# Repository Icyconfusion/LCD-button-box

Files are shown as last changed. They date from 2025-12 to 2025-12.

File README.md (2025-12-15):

# LCD-button-box
A DIY stream deck style button box using a 3.5" LCD, tact switches and an ESP32 Devkit V1.

The button box uses an LCD seated at the bottom of the case. Above that, a PCB is suspended, containing the necessary tact switches. The PCB has square cutout holes to show the LCD image through. To press the buttons, there is a 3d printed stand on each set of 4 switches (one button), holding a clear acrylic square. Through this mechanism, the LCD is visible, and pressing the acylic presses the tact switches, registering a keypress. The bottom right button functions as a change layer button, where pressing that will cycle the button box to a new 'layer', with different icons and key outputs. 

The case is made using two parts, a base and a top. The base has 4 'legs' inside it to hold the lcd. 
 
Above that, there is a perimeter ledge for the PCB to sit on. 

The top attaches to the base using 4xM3 heatset inserts. 



The ESP32 and switches are soldered to the PCB, and headers are soldered in place of the LCD. Jumper wires connect these headers down, underneath the LCD and into the pins on the bottom of the LCD.



The button box connects to devices by bluetooth, but requires a micro usb power source. The button box outputs macros using a combination of CTRL, SHIFT, ALT and F14+ keys to ensure unique macros.

Bill of materials
1x ESP32 Devkit V1

24x Tactile switch 6x6x5mm

1x 3.5" TFT 480x320 LCD screen

1x 40 pin male headers

20x Female - female jumper wires

3d printed parts

Acrylic sheet

PCB

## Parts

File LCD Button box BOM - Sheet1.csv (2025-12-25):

Product name | Quantity | Description | Supplier | Cost (USD) | Link
Tact Switch | 24 | A 6x6x5mm tactile switch. Comes in a pack of 50. | TEMU | 2.13 | https://www.temu.com/au/50pcs-6-6-5mm-tactile--pin-micro-push-button-g-601099520633185.html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
LCD | 1 | 3.5" TFT 480x320 LCD screen - Amazon is the cheapest place for this product - cheaper than TEMU and aliexpress | Amazon AU | 16.86 | https://www.amazon.com.au/3-5inch-480X320-Display-Module-Without/dp/B0DB25WKB3
Header | 1 | 1x40 pin 2.54mm male pin header | Jaycar Electronics | 0.73 | https://www.jaycar.com.au/40-pin-header-terminal-strip/p/HM3212
Acrylic SHeet | 1 | An A5 acrylic sheet to be cut into small squares - Amazon is cheaper than aliexpress and temu for this product | Amazon AU | 8.26 | https://www.amazon.com.au/gp/product/B0FC6TMFG9/ref=ox_sc_act_image_1?smid=A3H79FG5MEROR8&th=1

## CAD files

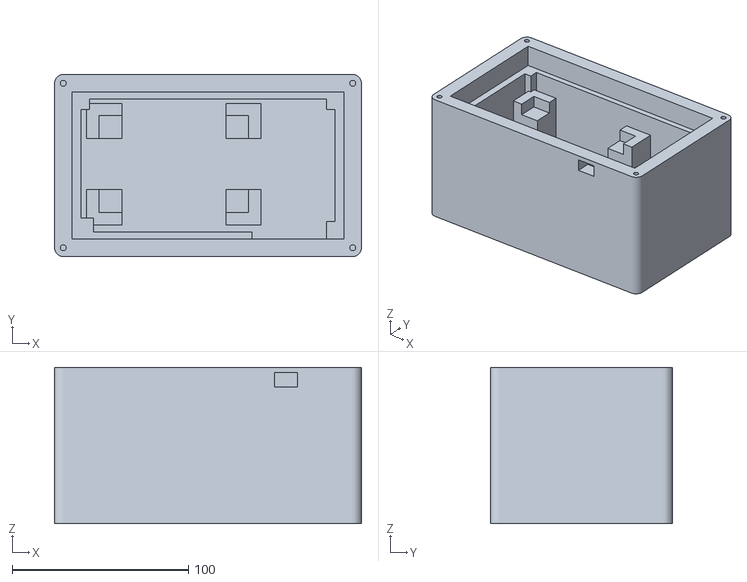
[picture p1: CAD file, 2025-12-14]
CAD/lcd button box case base.stl
174.2 x 103.3 x 88.6

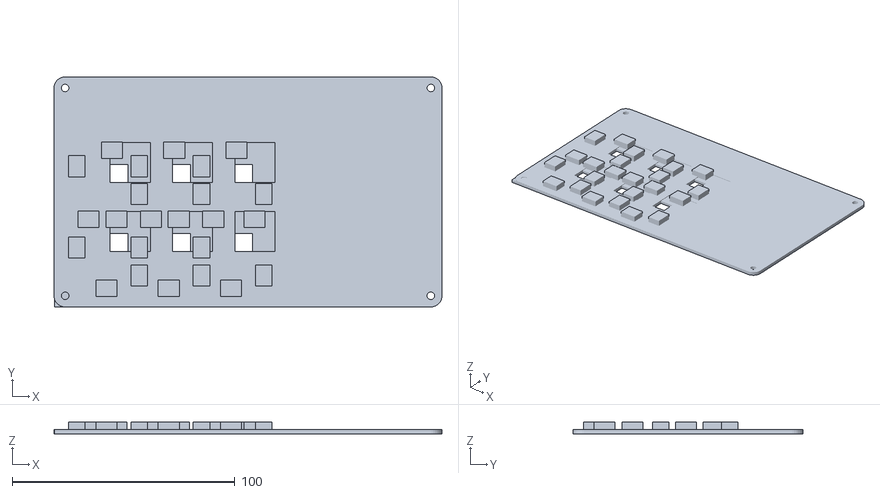
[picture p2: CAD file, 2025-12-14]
CAD/LCD Button box top.stl
174.2 x 103.4 x 5.20

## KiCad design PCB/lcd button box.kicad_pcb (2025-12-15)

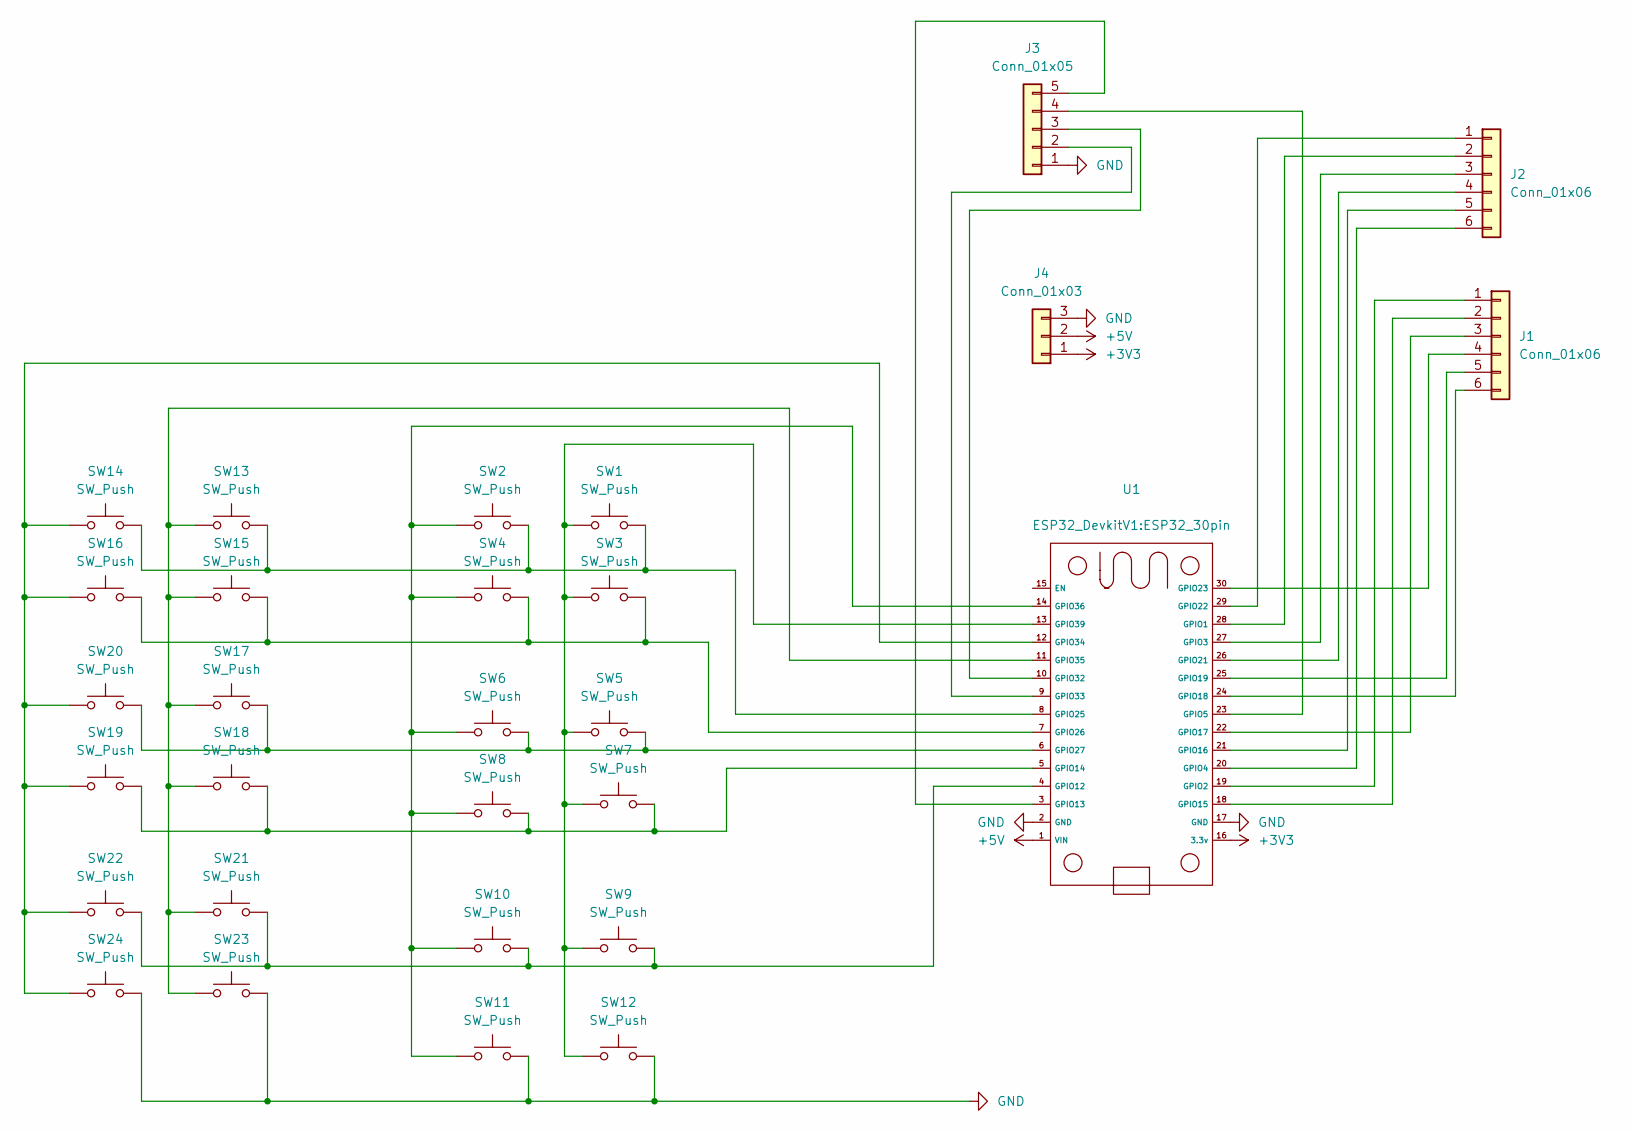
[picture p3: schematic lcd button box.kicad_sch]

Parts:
J1, J2: Conn_01x06; PinHeader_1x06_P2.54mm_Vertical
J3: Conn_01x05; PinHeader_1x05_P2.54mm_Vertical
J4: Conn_01x03; PinHeader_1x03_P2.54mm_Vertical
SW1, SW2, SW3, SW4, SW5, SW6, SW7, SW8, SW9, SW10, SW11, SW12, SW13, SW14, SW15, SW16, SW17, SW18, SW19, SW20, SW21, SW22, SW23, SW24: SW_Push; SW_PUSH_6mm
U1: ESP32_30pin

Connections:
+3V3: J4.1, U1.16 (3.3v)
+5V: J4.2, U1.1 (VIN)
GND: J3.1, J4.3, SW11.2, SW12.2, SW23.2, SW24.2, U1.2 (GND), U1.17 (GND)
unnamed: J1.1, U1.19 (GPIO2)
unnamed: J1.2, U1.18 (GPIO15)
unnamed: J1.3, U1.22 (GPIO17)
unnamed: J1.4, U1.30 (GPIO23)
unnamed: J1.5, U1.25 (GPIO19)
unnamed: J1.6, U1.24 (GPIO18)
unnamed: J2.1, U1.29 (GPIO22)
unnamed: J2.2, U1.28 (GPIO1)
unnamed: J2.3, U1.27 (GPIO3)
unnamed: J2.4, U1.26 (GPIO21)
unnamed: J2.5, U1.21 (GPIO16)
unnamed: J2.6, U1.20 (GPIO4)
unnamed: J3.2, U1.9 (GPIO33)
unnamed: J3.3, U1.10 (GPIO32)
unnamed: J3.4, U1.23 (GPIO5)
unnamed: J3.5, U1.3 (GPIO13)
unnamed: SW9.2, SW10.2, SW21.2, SW22.2, U1.4 (GPIO12)
unnamed: SW7.2, SW8.2, SW18.2, SW19.2, U1.5 (GPIO14)
unnamed: SW1.2, SW2.2, SW13.2, SW14.2, U1.8 (GPIO25)
unnamed: SW3.2, SW4.2, SW15.2, SW16.2, U1.7 (GPIO26)
unnamed: SW5.2, SW6.2, SW17.2, SW20.2, U1.6 (GPIO27)
unnamed: SW14.1, SW16.1, SW19.1, SW20.1, SW22.1, SW24.1, U1.12 (GPIO34)
unnamed: SW13.1, SW15.1, SW17.1, SW18.1, SW21.1, SW23.1, U1.11 (GPIO35)
unnamed: SW2.1, SW4.1, SW6.1, SW8.1, SW10.1, SW11.1, U1.14 (GPIO36)
unnamed: SW1.1, SW3.1, SW5.1, SW7.1, SW9.1, SW12.1, U1.13 (GPIO39)

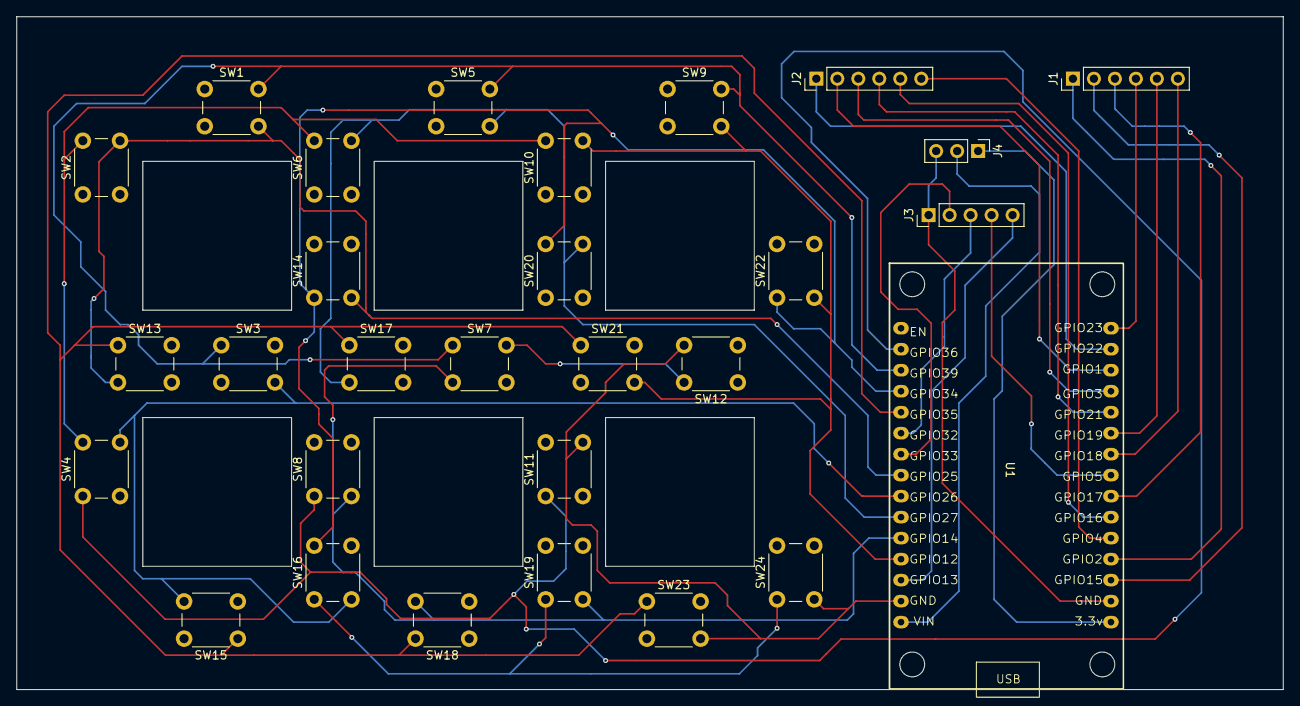
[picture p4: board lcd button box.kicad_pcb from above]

Board: 2 copper layers, 153.2 x 81.4 mm, 29 parts (0 on the bottom side), 28 nets.

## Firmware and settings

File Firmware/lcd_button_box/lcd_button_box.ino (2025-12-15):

// hello world

#include <BleKeyboard.h>
BleKeyboard bleKeyboard;

#include <TFT_eSPI.h>
#include <SPI.h>
#include <SD.h>

TFT_eSPI tft = TFT_eSPI();

#define SD_CS 17  // Change if you wired differently

#define ICON_SIZE 104


// Matrix pin definitions
//Column pins

#define col_pin1 39
#define col_pin2 36
#define col_pin3 35
#define col_pin4 34

// Row pins

#define row_pin1 25
#define row_pin2 26
#define row_pin3 27
#define row_pin4 14
#define row_pin5 12
// row 6 is GND

int layerstate = 1;

void setup() {
  // put your setup code here, to run once:

bleKeyboard.begin(); // start ble keyboard

// COlumn pins as inputs
pinMode(col_pin1, INPUT);
pinMode(col_pin2, INPUT);
pinMode(col_pin3, INPUT);
pinMode(col_pin4, INPUT);

// Row pins as output

pinMode(row_pin1, OUTPUT);
pinMode(row_pin2, OUTPUT);
pinMode(row_pin3, OUTPUT);
pinMode(row_pin4, OUTPUT);
pinMode(row_pin5, OUTPUT);

 // -------- LCD INITIALIZATION --------

  // Initialize the LCD
  tft.init();

  // Set screen orientation
  // 0 = portrait, 1 = landscape, 2 = upside-down, 3 = mirrored
  tft.setRotation(1);

  // Fill the entire screen with black color
  tft.fillScreen(TFT_BLACK);

  // Set text color to white with black background
  tft.setTextColor(TFT_WHITE, TFT_BLACK);

  // Set text size (2 = medium size)
  tft.setTextSize(2);

  // Set the position of the text cursor (x, y)
  tft.setCursor(10, 10);

  // Print text to the LCD
  tft.println("LCD OK");

  // -------- SD CARD INITIALIZATION --------

  // Try to initialize the SD card
  // Uses SPI and the chip select pin defined earlier
  if (!SD.begin(SD_CS)) {

    // If SD initialization fails, move cursor lower
    tft.setCursor(10, 40);

    // Set text color to red
    tft.setTextColor(TFT_RED, TFT_BLACK);

    // Print error message to LCD
    tft.println("SD FAIL");

    // Stop the program forever if SD fails
    while (1);
  }
// If SD card initializes correctly, move cursor
  tft.setCursor(10, 40);

  // Change text color to green
  tft.setTextColor(TFT_GREEN, TFT_BLACK);

  // Print success message
  tft.println("SD OK");

  // -------- DRAW ICONS FROM SD CARD --------

  // Draw first icon at x=13, y=13 - top left corner with 2mm margin from edge
  drawBmp("/icon1.bmp", 13, 13);

  // Draw second icon at x=195, y=13 - 30mm from left top corner
  drawBmp("/icon2.bmp", 195, 13);

  // Draw third icon at x=220, y=80
  drawBmp("/icon3.bmp", 377, 13);

  // Draw fourth icon
  drawBmp("/icon4.bmp", 13, 214);

  // Draw fifth icon
  drawBmp("/icon5.bmp", 195, 214);

  // Draw sixth icon
  drawBmp("/changeicon.bmp", 377, 214);

  layerstate = 1;
}


void loop() {
  // put your main code here, to run repeatedly:
//write row high, then check column

//Button 1
digitalWrite(row_pin1, HIGH);
if(digitalRead(col_pin1) == HIGH || digitalRead(col_pin2) == HIGH || digitalRead(col_pin3) == HIGH || digitalRead(col_pin4) == HIGH){
bleKeyboard.press(KEY_LEFT_CTRL);
bleKeyboard.press(KEY_LEFT_SHIFT);
bleKeyboard.write(KEY_F14);
bleKeyboard.releaseAll();
}
digitalWrite(row_pin1, LOW);

//Button 2
digitalWrite(row_pin2, HIGH);
if(digitalRead(col_pin1) == HIGH || digitalRead(col_pin2) == HIGH || digitalRead(col_pin3) == HIGH || digitalRead(col_pin4) == HIGH){
bleKeyboard.press(KEY_LEFT_CTRL);
bleKeyboard.press(KEY_LEFT_SHIFT);
bleKeyboard.write(KEY_F15);
bleKeyboard.releaseAll();
}
digitalWrite(row_pin2, LOW);

//Button 3
digitalWrite(row_pin3, HIGH);
if(digitalRead(col_pin1) == HIGH || digitalRead(col_pin2) == HIGH || digitalRead(col_pin3) == HIGH || digitalRead(col_pin4) == HIGH){
bleKeyboard.press(KEY_LEFT_CTRL);
bleKeyboard.press(KEY_LEFT_SHIFT);
bleKeyboard.write(KEY_F16);
bleKeyboard.releaseAll();
}
digitalWrite(row_pin3, LOW);

//Button 4
digitalWrite(row_pin4, HIGH);
if(digitalRead(col_pin1) == HIGH || digitalRead(col_pin2) == HIGH || digitalRead(col_pin3) == HIGH || digitalRead(col_pin4) == HIGH){
bleKeyboard.press(KEY_LEFT_CTRL);
bleKeyboard.press(KEY_LEFT_SHIFT);
bleKeyboard.write(KEY_F17);
bleKeyboard.releaseAll();
}
digitalWrite(row_pin4, LOW);

//Button 5
digitalWrite(row_pin5, HIGH);
if(digitalRead(col_pin1) == HIGH || digitalRead(col_pin2) == HIGH || digitalRead(col_pin3) == HIGH || digitalRead(col_pin4) == HIGH){
bleKeyboard.press(KEY_LEFT_CTRL);
bleKeyboard.press(KEY_LEFT_SHIFT);
bleKeyboard.write(KEY_F14);
bleKeyboard.releaseAll();
}
digitalWrite(row_pin5, LOW);

//Button 6
//Change screen button

if(digitalRead(col_pin1) == HIGH || digitalRead(col_pin2) == HIGH || digitalRead(col_pin3) == HIGH || digitalRead(col_pin4) == HIGH){
// change to next LCD screen
layerstate++;
}

if (layerstate > 3){
  layerstate = 1;
}

if (layerstate == 1){
  // Draw layer 1 icons
  drawBmp("/icon1.bmp", 13, 13);
  drawBmp("/icon2.bmp", 195, 13);
  drawBmp("/icon3.bmp", 377, 13);
  drawBmp("/icon4.bmp", 13, 214);
  drawBmp("/icon5.bmp", 195, 214);
  drawBmp("/changeicon.bmp", 377, 214);
}

if (layerstate == 2){
  // Draw layer 2 icons
  drawBmp("/icon6.bmp", 13, 13);
  drawBmp("/icon7.bmp", 195, 13);
  drawBmp("/icon8.bmp", 377, 13);
  drawBmp("/icon9.bmp", 13, 214);
  drawBmp("/icon10.bmp", 195, 214);
  drawBmp("/changeicon.bmp", 377, 214);
}

if (layerstate == 3){
  // Draw layer 3 icons
  drawBmp("/icon11.bmp", 13, 13);
  drawBmp("/icon12.bmp", 195, 13);
  drawBmp("/icon13.bmp", 377, 13);
  drawBmp("/icon14.bmp", 13, 214);
  drawBmp("/icon15.bmp", 195, 214);
  drawBmp("/changeicon.bmp", 377, 214);
}

}

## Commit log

2025-12-14 Added CAD files
    [LCD Button box top.stl, lcd button box case base.stl]
2025-12-15 Added necessary files
    [LCD Button box top.stl, lcd button box case base.stl, lcd button box.kicad_pcb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]
2025-12-16 Added BOM
    [LCD Button box BOM - Sheet1.csv]
2025-12-16 Update LCD Button box BOM - Sheet1.csv
    [LCD Button box BOM - Sheet1.csv]
